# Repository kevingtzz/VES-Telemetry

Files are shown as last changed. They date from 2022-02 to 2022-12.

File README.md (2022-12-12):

## VES-Telemetry 🚀
Telemetry system for electro-solar vehicle VES-KRATOS
## Hardware 🔧
API frames reception and emission for Zigbee mesh topology architecture implemented on Xbee.
CAN protocol data extraction, processing and emission (Low level).
## Software ⚙️
Multi platform aplication on Electron JS for GPS geolocation and electro-solar vehicle data monitoring on real time.
## Initialization:
* Install dependencies with npm install.
* Install RethinkDB, if you have macOS with homebrew just type on your terminal "brew update && brew install rethinkdb".
* Create the database, go to localhost:8080 and create a database with this name "KRATOS-VES".

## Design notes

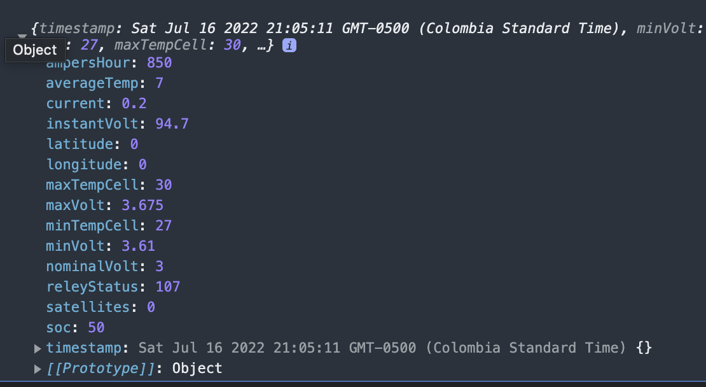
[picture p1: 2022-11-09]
Hardware/PCB/Receiver/Screen Shot 2022-07-16 at 21.05.58.png

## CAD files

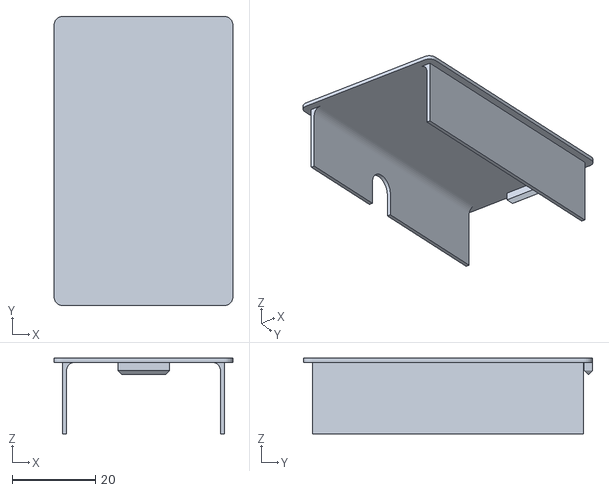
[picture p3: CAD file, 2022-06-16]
Hardware/Cases/Receiver/tapa.stl
43.0 x 69.5 x 18.2

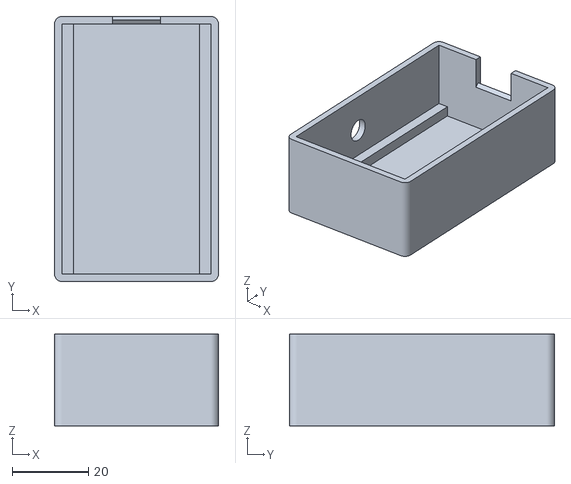
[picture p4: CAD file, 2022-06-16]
Hardware/Cases/Receiver/case.stl
43.0 x 69.5 x 24.0

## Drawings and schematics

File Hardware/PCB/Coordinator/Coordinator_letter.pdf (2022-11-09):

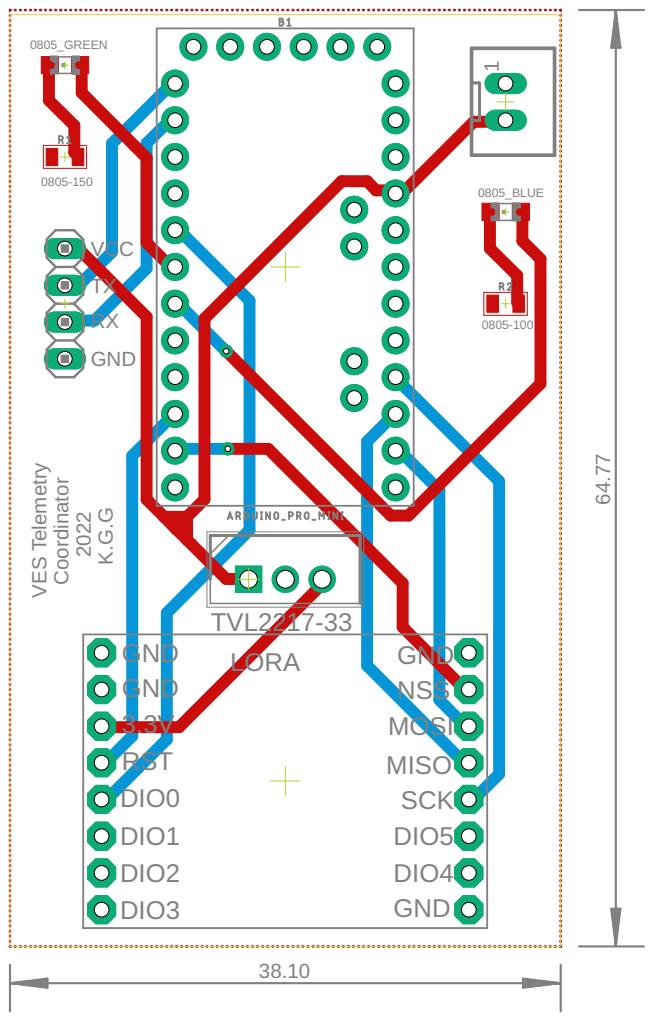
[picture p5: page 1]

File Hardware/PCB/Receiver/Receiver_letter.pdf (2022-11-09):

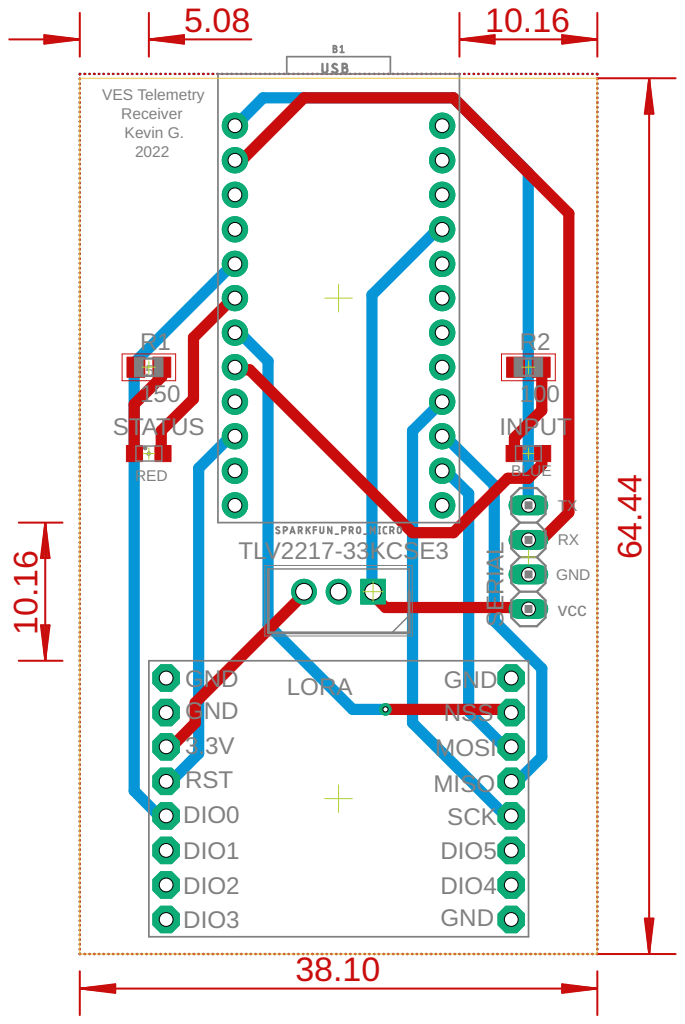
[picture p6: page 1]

VES Telemetry Receiver Kevin G. 2022

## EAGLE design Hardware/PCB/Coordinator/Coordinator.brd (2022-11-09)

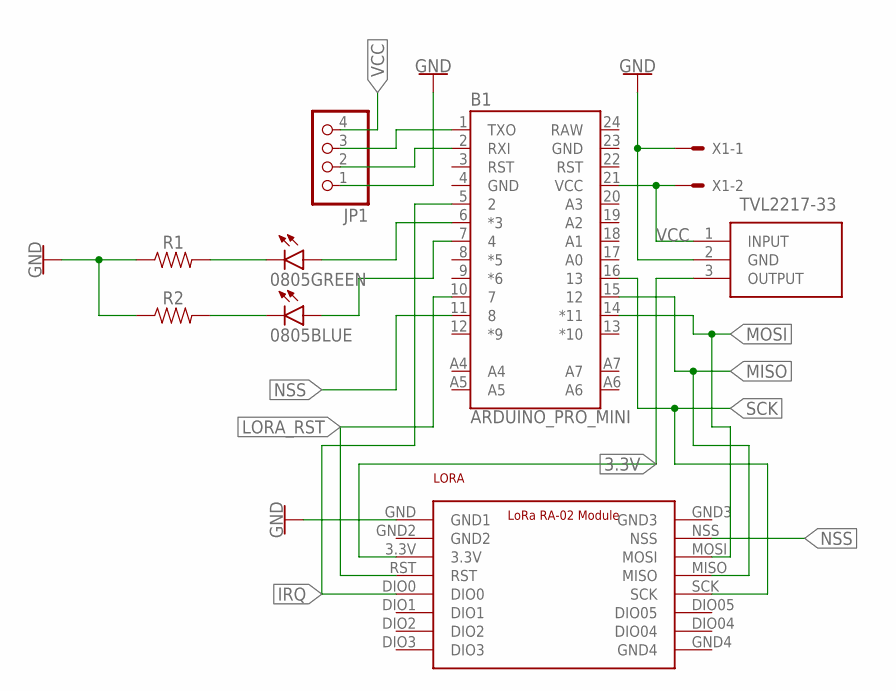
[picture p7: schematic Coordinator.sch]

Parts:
0805BLUE, 0805GREEN: LEDCHIPLED_0805; CHIPLED_0805
B1: ARDUINO_PRO_MINI
JP1: PINHD-1X4; 1X04
LORA: LORA_RA-02_MODULE; LORA_RA-02_MODULE_FOOTPRINT
R1, R2: 0805
TVL2217-33: TLV2217-33KCSE3; TO254P470X1016X1965-3P
X1: JST-XH-02-PIN-LONG-PAD; JST-XH-02-PACKAGE-LONG-PAD

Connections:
3.3V: LORA.3.3V, TVL2217-33.3 (OUTPUT)
GND: B1.4 (GND), B1.23 (GND), JP1.1, LORA.GND (GND1), R1.1, R2.1, TVL2217-33.2 (GND), X1.1
IRQ: B1.5 (2), LORA.DIO0
LORA_RST: B1.10 (7), LORA.RST
MISO: B1.15 (12), LORA.MISO
MOSI: B1.14 (*11), LORA.MOSI
unnamed: B1.2 (RXI), JP1.2
unnamed: B1.1 (TXO), JP1.3
unnamed: 0805GREEN.A, B1.6 (*3)
unnamed: 0805BLUE.A, B1.7 (4)
unnamed: 0805GREEN.C, R1.2
unnamed: 0805BLUE.C, R2.2
NSS: B1.11 (8), LORA.NSS
RAW: B1.24 (RAW)
SCK: B1.16 (13), LORA.SCK
VCC: B1.21 (VCC), JP1.4, TVL2217-33.1 (INPUT), X1.2

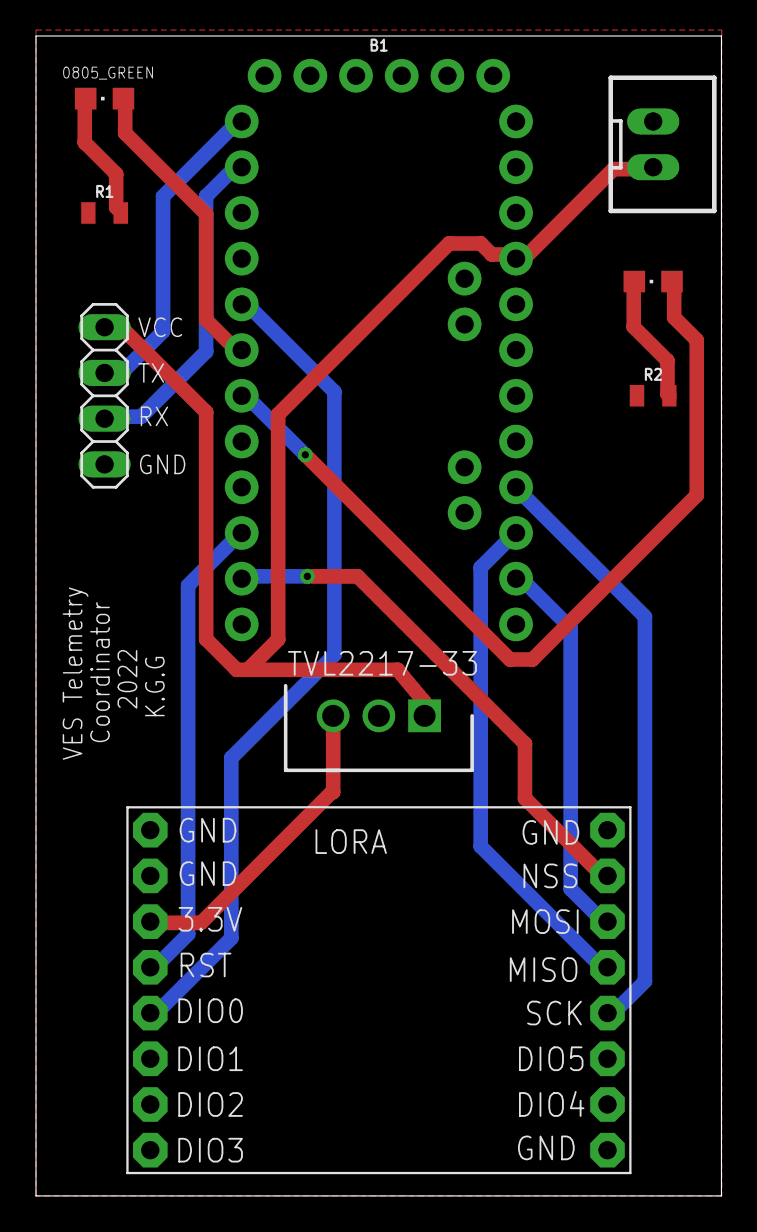
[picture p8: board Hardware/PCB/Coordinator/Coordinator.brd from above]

Board: 2 copper layers, 38.1 x 64.4 mm, 9 parts (0 on the bottom side), 15 nets.

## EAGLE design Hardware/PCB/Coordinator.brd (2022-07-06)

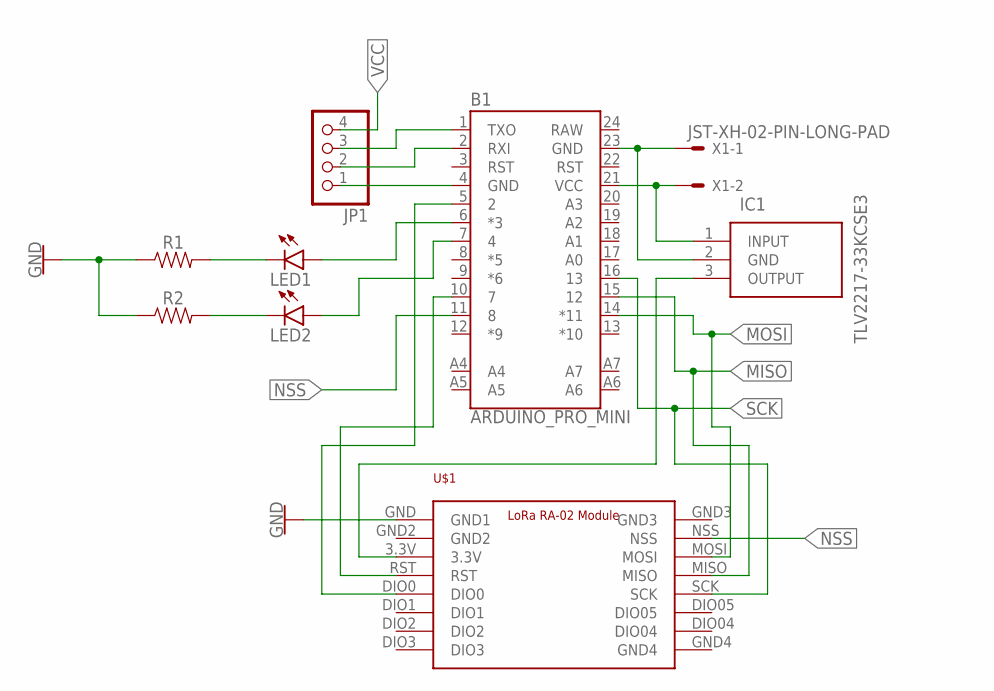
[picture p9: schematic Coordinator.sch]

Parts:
B1: ARDUINO_PRO_MINI
IC1: TLV2217-33KCSE3; TO254P470X1016X1965-3P
JP1: PINHD-1X4; 1X04
LED1, LED2: LEDCHIPLED_0805; CHIPLED_0805
R1, R2: 0805
U$1: LORA_RA-02_MODULE; LORA_RA-02_MODULE_FOOTPRINT
X1: JST-XH-02-PIN-LONG-PAD; JST-XH-02-PACKAGE-LONG-PAD

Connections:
GND: R1.1, R2.1, U$1.GND (GND1)
MISO: B1.15 (12), U$1.MISO
MOSI: B1.14 (*11), U$1.MOSI
unnamed: B1.23 (GND), IC1.2 (GND), X1.1
unnamed: B1.21 (VCC), IC1.1 (INPUT), X1.2
unnamed: IC1.3 (OUTPUT), U$1.3.3V
unnamed: B1.4 (GND), JP1.1
unnamed: B1.2 (RXI), JP1.2
unnamed: B1.1 (TXO), JP1.3
unnamed: B1.5 (2), U$1.DIO0
unnamed: B1.10 (7), U$1.RST
unnamed: B1.6 (*3), LED1.A
unnamed: B1.7 (4), LED2.A
unnamed: LED1.C, R1.2
unnamed: LED2.C, R2.2
NSS: B1.11 (8), U$1.NSS
RAW: B1.24 (RAW)
SCK: B1.16 (13), U$1.SCK
VCC: JP1.4

Board: 2 copper layers, 9 parts (0 on the bottom side), 17 nets, no tracks yet.

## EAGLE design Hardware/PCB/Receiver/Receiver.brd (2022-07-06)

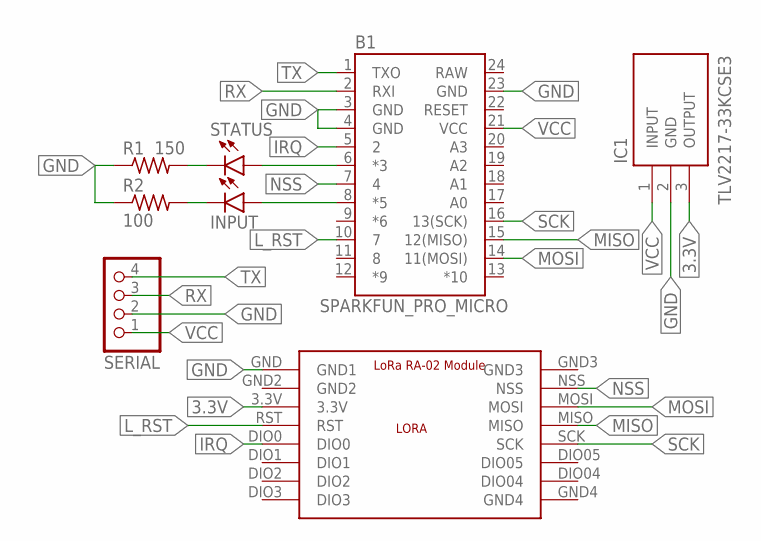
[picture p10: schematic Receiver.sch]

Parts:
B1: SPARKFUN_PRO_MICRO
IC1: TLV2217-33KCSE3; TO254P470X1016X1965-3P
INPUT: LEDSML0805; SML0805
LORA: LORA_RA-02_MODULE; LORA_RA-02_MODULE_FOOTPRINT
R1: 150; R0805
R2: 100; R0805
SERIAL: PINHD-1X4; 1X04
STATUS: LEDSML0805; SML0805

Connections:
3.3V: IC1.3 (OUTPUT), LORA.3.3V
GND: B1.3 (GND), B1.4 (GND), B1.23 (GND), IC1.2 (GND), LORA.GND (GND1), R1.1, R2.1, SERIAL.2
IRQ: B1.5 (2), LORA.DIO0
L_RST: B1.10 (7), LORA.RST
MISO: B1.15 (12(MISO)), LORA.MISO
MOSI: B1.14 (11(MOSI)), LORA.MOSI
unnamed: B1.6 (*3), STATUS.A
unnamed: B1.8 (*5), INPUT.A
unnamed: INPUT.C, R2.2
NSS: B1.7 (4), LORA.NSS
RAW: B1.24 (RAW)
RX: B1.2 (RXI), SERIAL.3
SCK: B1.16 (13(SCK)), LORA.SCK
STATUS: R1.2, STATUS.C
TX: B1.1 (TXO), SERIAL.4
VCC: B1.21 (VCC), IC1.1 (INPUT), SERIAL.1

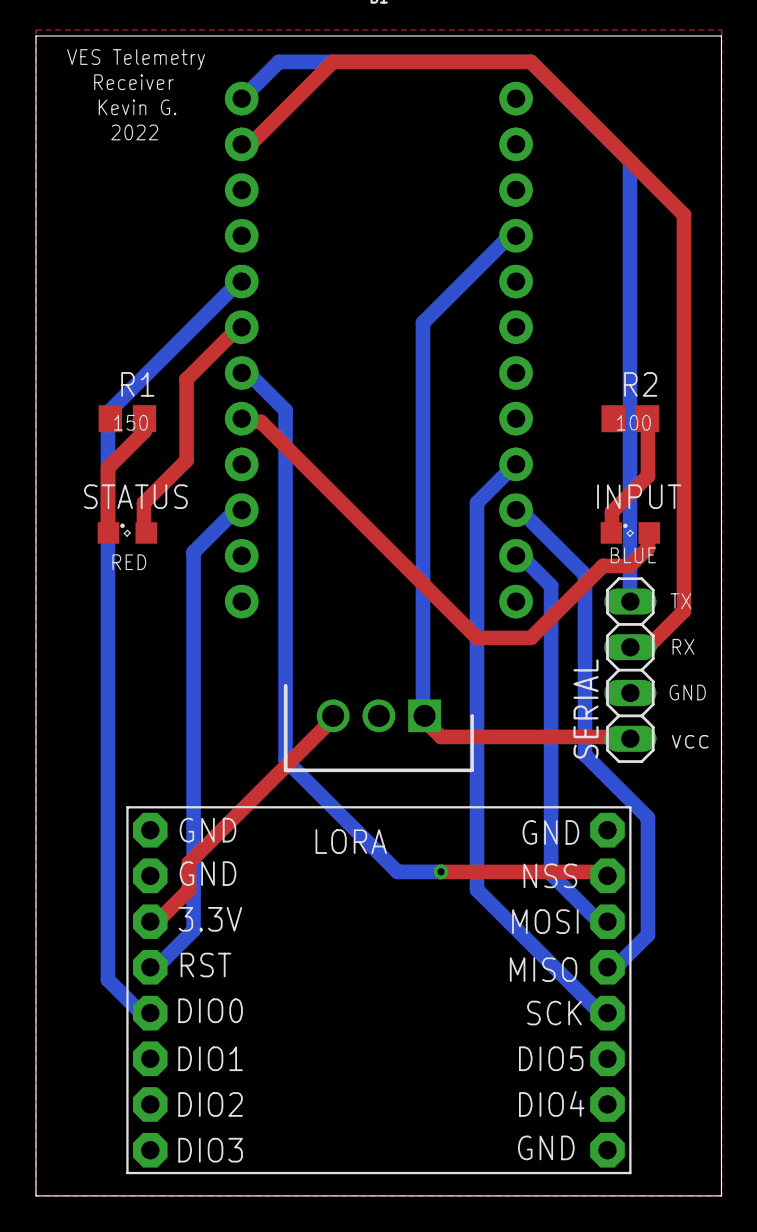
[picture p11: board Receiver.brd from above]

Board: 2 copper layers, 38.1 x 64.4 mm, 8 parts (0 on the bottom side), 15 nets.

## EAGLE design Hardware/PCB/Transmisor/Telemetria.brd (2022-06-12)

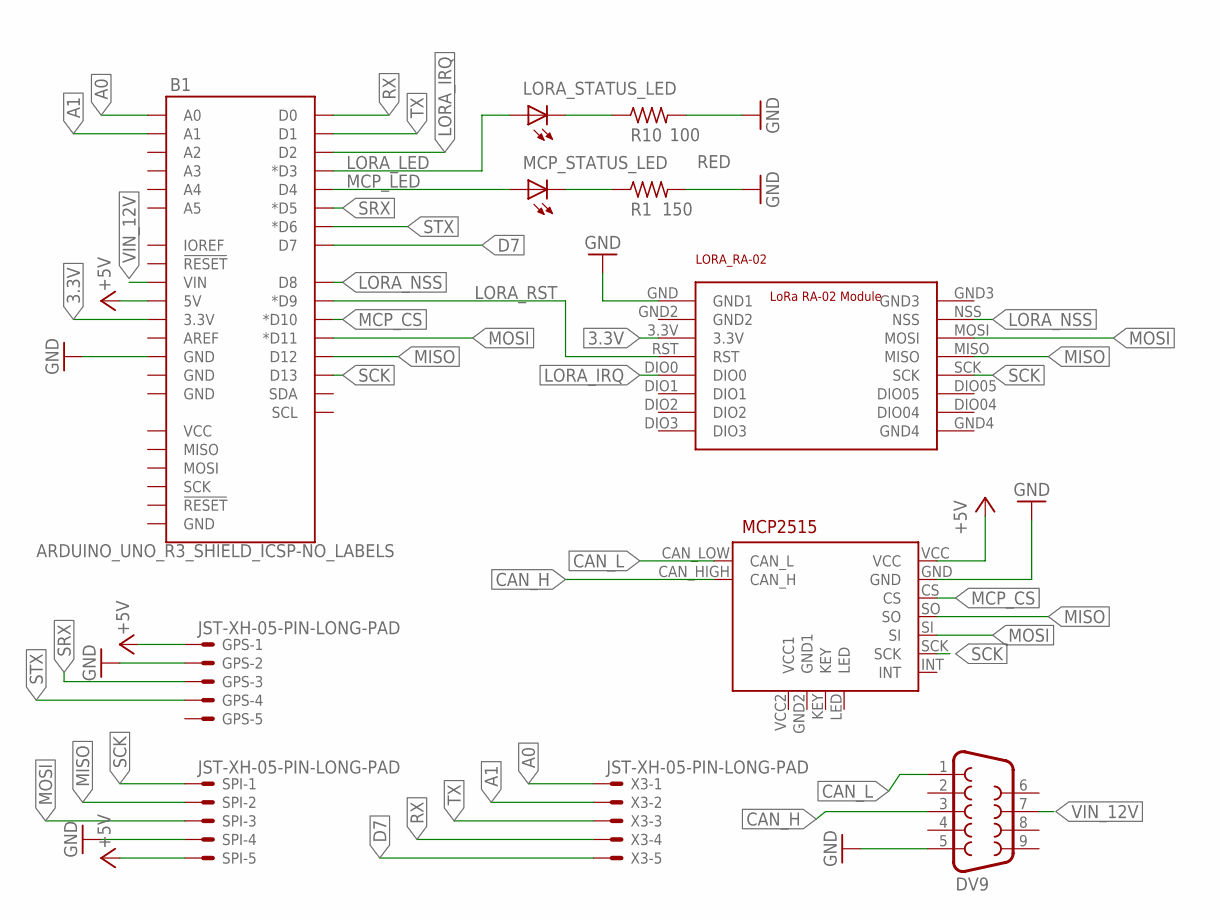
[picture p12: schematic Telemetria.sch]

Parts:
B1: ARDUINO_UNO_R3_SHIELD_ICSP-NO_LABELS; UNO_R3_SHIELD_ICSP_NOLABELS
GPS: JST-XH-05-PIN-LONG-PAD; JST-XH-05-PACKAGE-LONG-PAD
LORA_RA-02: LORA_RA-02_MODULE; LORA_RA-02_MODULE_FOOTPRINT
LORA_STATUS_LED: BLUE; CHIP-LED0805
MCP2515: MCP2515
MCP_STATUS_LED: RED; CHIP-LED0805
R1: 150; M0805
R10: 100; M0805
SPI: JST-XH-05-PIN-LONG-PAD; JST-XH-05-PACKAGE-LONG-PAD
X3: JST-XH-05-PIN-LONG-PAD; JST-XH-05-PACKAGE-LONG-PAD
X4: DV9; F09H

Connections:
3.3V: B1.3.3V, LORA_RA-02.3.3V
+5V: B1.5V, GPS.1, MCP2515.VCC, SPI.5
A0: B1.A0, X3.1
A1: B1.A1, X3.2
CAN_H: MCP2515.CAN_HIGH (CAN_H), X4.3
CAN_L: MCP2515.CAN_LOW (CAN_L), X4.1
D7: B1.D7, X3.5
GND: B1.GND@2 (GND), GPS.2, LORA_RA-02.GND (GND1), MCP2515.GND, R1.2, R10.2, SPI.4, X4.5
LORA_IRQ: B1.D2, LORA_RA-02.DIO0
LORA_LED: B1.D3 (*D3), LORA_STATUS_LED.A
LORA_NSS: B1.D8, LORA_RA-02.NSS
LORA_RST: B1.D9 (*D9), LORA_RA-02.RST
MCP_CS: B1.D10 (*D10), MCP2515.CS
MCP_LED: B1.D4, MCP_STATUS_LED.A
MISO: B1.D12, LORA_RA-02.MISO, MCP2515.SO, SPI.2
MOSI: B1.D11 (*D11), LORA_RA-02.MOSI, MCP2515.SI, SPI.3
unnamed: LORA_STATUS_LED.C, R10.1
unnamed: MCP_STATUS_LED.C, R1.1
RX: B1.RX (D0), X3.4
SCK: B1.D13, LORA_RA-02.SCK, MCP2515.SCK, SPI.1
SRX: B1.D5 (*D5), GPS.3
STX: B1.D6 (*D6), GPS.4
TX: B1.TX (D1), X3.3
VIN_12V: B1.VIN, X4.7

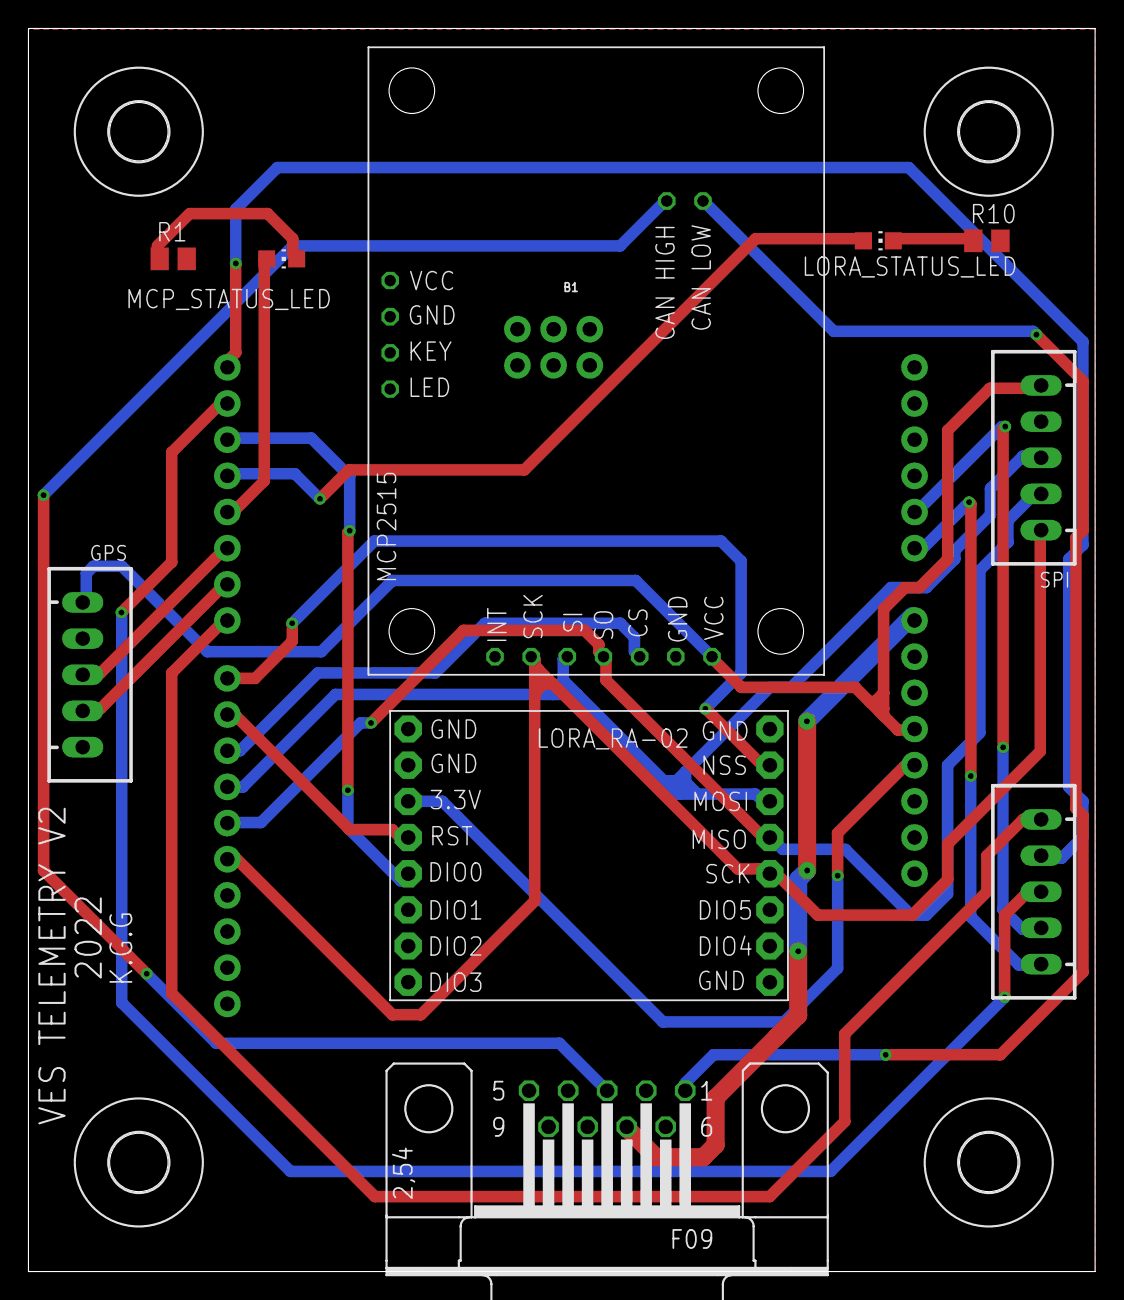
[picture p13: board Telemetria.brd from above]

Board: 2 copper layers, 74.9 x 87.3 mm, 15 parts (0 on the bottom side), 24 nets.

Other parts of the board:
U$1, U$2, U$3, U$4: 4,1

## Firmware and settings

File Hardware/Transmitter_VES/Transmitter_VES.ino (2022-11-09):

#include "constants.h"
#include <SPI.h>
#include <mcp_can.h>
#include <LoRa.h>
#include <TinyGPSPlus.h>
#include <SoftwareSerial.h>

MCP_CAN CAN(CAN_SPI_CS_PIN);
byte data[DATA_LENGTH] = { 0 };
byte frame[FRAME_LENGTH] = { 0 };
byte buf[DATA_LENGTH];

TinyGPSPlus gps;
SoftwareSerial gps_ss(GPS_RX_PIN, GPS_TX_PIN);

long lat = 0;
long lng = 0;

unsigned int current_time = 0;
unsigned int led_lora_current_time = 0;
unsigned int final_time = 0;
unsigned int led_lora_final_time = 0;

void fill_data_can() {
  unsigned char len = 0;
  unsigned char buf[8];

  CAN.readMsgBuf(&len, buf);

  unsigned long canId = CAN.getCanId();
//  Serial.println(canId);

  if (canId == 0x3CB) {
//    Serial.println("0x3CB data");
    data[0] = buf[2]; // most significant minVolt byte
    data[1] = buf[3]; // least significant minVolt byte
    data[2] = buf[4]; // most significant maxVolt byte
    data[3] = buf[5]; // least significant maxVolt byte
    data[4] = buf[6]; // minimum temperature
    data[5] = buf[7]; // maximum temperature
  }
  if (canId == 0x03B) {
//    Serial.println("0x03B data");
    data[6] = buf[0]; // most significant current byte
    data[7] = buf[1]; // least significant current byte
    data[8] = buf[2]; // most significant instantVolt byte
    data[9] = buf[3]; // least significant instantVolt byte
    data[10] = buf[4]; // Ampers per hour most significant byte
    data[11] = buf[5]; // Ampers per hour least significant byte
    data[12] = buf[6]; // SOC
  }
  if (canId == 0x653) {
//    Serial.println("0x653 data");
    data[13] = buf[0]; // reley status
    data[14] = buf[4]; // average temp - div by 2
  }
  if (canId == 0x651) {
//    Serial.println("0x651 data");
    data[15] = buf[4]; // Nominal volt most significant byte
    data[16] = buf[5]; // Nominal volt leat significant byte
  }
  if (canId == 0x3A) {
    Serial.println("0x03A data");
  }
}

void fill_data_gps() {
  while(gps_ss.available() > 0) {
    gps.encode(gps_ss.read());
  }
  if (gps.satellites.isValid() && gps.satellites.isUpdated()) {
    data[17] = gps.satellites.value();
  } else if (gps.location.isValid() && gps.location.isUpdated()) {
    lat = gps.location.lat()*pow(10, 6);
    lng = gps.location.lng()*pow(10, 6);
    data[18] = (0x000000FF)&lat;
    data[19] = ((0x0000FF00)&lat) >> 8;
    data[20] = ((0x00FF0000)&lat) >> 16;
    data[21] = ((0xFF000000)&lat) >> 24;
    data[22] = (0x000000FF)&lng;
    Serial.print(data[22]);
    Serial.print(",");
    data[23] = ((0x0000FF00)&lng) >> 8;
    Serial.print(data[23]);
    Serial.print(",");
    data[24] = ((0x00FF0000)&lng) >> 16;
    Serial.print(data[24]);
    Serial.print(",");
    data[25] = ((0xFF000000)&lng) >> 24;
    Serial.print(data[25]);
    Serial.println("");
  }
}

void fillDataTest() {
  data[0] = 0x03;
  data[12] = 50;
  data[DATA_LENGTH - 1] = 0x03;
}

//byte checksum(byte data[]) {
//  byte checksum = 0x00;
//  for (int i = 0; i < DATA_LENGTH; i++) {
//      checksum += data[i];
//  }
//  return checksum;
//}

void fillFrame() {
  frame[0] = NETWORK_ID;
  frame[1] = TRANSMITTER_ADDRESS;
  frame[2] = DATA_LENGTH;
  for (int i = 3; i < FRAME_LENGTH; i++) {
    frame[i] = data[i - 3];
  }
//  frame[FRAME_LENGTH - 1] = checksum(data);
}

void sendFrame() {
  digitalWrite(LORA_STATUS_LED, HIGH);
  
  fillFrame();
//  printFrame();
  Serial.println("Sending package...");
  LoRa.beginPacket();
  LoRa.write(frame, FRAME_LENGTH);
  LoRa.endPacket();
}

//void printFrame() {
//  Serial.print("CheckSum: ");
//  Serial.println(frame[FRAME_LENGTH - 1]);
//}

void setup() {
  pinMode(LORA_STATUS_LED, OUTPUT);
  pinMode(MCP_STATUS_LED, OUTPUT);
//  pinMode(2, INPUT);

  LoRa.setPins(LORA_CS_PIN, LORA_RESET_PIN, LORA_IRQ_PIN);

  Serial.begin(SERIAL_BAUD_RATE);
  while(!Serial);
  gps_ss.begin(GPS_BAUD_RATE);

  if (!LoRa.begin(LORA_FREQUENCY)) {
    Serial.println("Starting LoRa failed!");
    while (1);
  }
  Serial.println("Starting LoRa Successfull!");
  digitalWrite(LORA_STATUS_LED, HIGH);
  LoRa.setTxPower(20);

  while (CAN_OK != CAN.begin(CAN_500KBPS)) {
    Serial.println("CAN init failed!!");
    delay(100);
  }
  Serial.println("CAN ok");
  digitalWrite(MCP_STATUS_LED, HIGH);
}

void loop() {
  if (CAN_MSGAVAIL == CAN.checkReceive()) {
    fill_data_can();
  }

  if (gps_ss.available() > 0) {
      fill_data_gps();
  }

  current_time = millis();
  led_lora_current_time = millis();
  
  if (current_time - final_time > 500) {
//    fillDataTest();
    sendFrame();
    memset(data, 0, DATA_LENGTH); // reset data vecto to 0
    final_time = current_time;
  }

  if (led_lora_current_time - led_lora_final_time > 1000) {
    digitalWrite(LORA_STATUS_LED, LOW);
    led_lora_final_time = led_lora_current_time;  
  }
}

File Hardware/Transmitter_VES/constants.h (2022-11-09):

//========================== Pins ==============================//

#define CAN_SPI_CS_PIN 10
#define LORA_CS_PIN 8
#define LORA_RESET_PIN 9
#define LORA_IRQ_PIN 2
#define LORA_STATUS_LED 3
#define MCP_STATUS_LED 4
#define GPS_RX_PIN 5
#define GPS_TX_PIN 6

//========================== Settings ==============================//

#define SERIAL_BAUD_RATE 9600
#define GPS_BAUD_RATE 9600
#define DATA_LENGTH 26
#define FRAME_LENGTH DATA_LENGTH + 3

//========================== Mesh settings ========================//

#define LORA_FREQUENCY 433E6
#define TRANSMITTER_ADDRESS 0x1
#define COORDINATOR_ADDRESS 0x2
#define RECEIVER_ADDRESS 0x3
#define NETWORK_ID 0x7

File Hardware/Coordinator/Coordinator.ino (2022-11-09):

#include <SPI.h>
#include <LoRa.h>
#include "constants.h"

unsigned int input_led_current_time = 0;
unsigned int input_led_final_time = 0;

void fillFrame(byte frame[], int data_length, int frame_length, byte data[]) {
  frame[0] = NETWORK_ID;
  frame[1] = COORDINATOR_ADDRESS;
  frame[2] = data_length;
  for (int i = 3; i < frame_length; i++) {
    frame[i] = data[i - 3];
  }
//  frame[FRAME_LENGTH - 1] = checksum(data);
}

void send_frame(byte frame[], int frame_length) {
//  printFrame();
  Serial.println("Sending package...");
  LoRa.beginPacket();
  LoRa.write(frame, frame_length);
  LoRa.endPacket();
}

void setup() {
  pinMode(LORA_INPUT_LED, OUTPUT);
  pinMode(LORA_STATUS_LED, OUTPUT);
  Serial.begin(SERIAL_BAUD_RATE);

  LoRa.setPins(LORA_CS_PIN, LORA_RESET_PIN, LORA_IRQ_PIN);
  if (!LoRa.begin(LORA_FREQUENCY)) {
    while (1);
    Serial.println("LoRa init failed!!");
  }
  Serial.println("Starting LoRa Successfull!");
  digitalWrite(LORA_STATUS_LED, HIGH);
}

void loop() {
  input_led_current_time = millis();
  int packetSize = LoRa.parsePacket();
  if (packetSize) {
    if (LoRa.read() == NETWORK_ID) {
      if (LoRa.read() == TRANSMITTER_ADDRESS) {
        digitalWrite(LORA_INPUT_LED, HIGH);
        int data_length = LoRa.read();
        int frame_length = data_length + 3;
        byte data[data_length] = { 0 };
        int index = 0;  
        while (LoRa.available()) {
          data[index] = LoRa.read();
          index++;
        }
        byte frame[data_length] = { 0 };
        fillFrame(frame, data_length, frame_length, data);
        send_frame(frame, frame_length);
      }
    }  
  }

  if (input_led_current_time - input_led_final_time > 1000) {
    digitalWrite(LORA_INPUT_LED, LOW);
    input_led_final_time = input_led_current_time;  
  }
}

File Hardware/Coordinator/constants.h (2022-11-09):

//========================== Pins ==============================//

#define LORA_CS_PIN 8
#define LORA_RESET_PIN 7
#define LORA_IRQ_PIN 2
#define LORA_INPUT_LED 4
#define LORA_STATUS_LED 3

//========================== Settings ==============================//

#define SERIAL_BAUD_RATE 9600

//========================== Mesh settings ========================//

#define LORA_FREQUENCY 433E6
#define TRANSMITTER_ADDRESS 0x1
#define COORDINATOR_ADDRESS 0x2
#define RECEIVER_ADDRESS 0x3
#define NETWORK_ID 0x7

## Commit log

2022-06-12 feat(Transmissor): PCB Transmissor finished
    [Telemetria.brd, Telemetria.sch]
2022-06-12 fix(transmissor): transmisson pcb updated
    [Telemetria.brd, Telemetria.sch]
2022-06-16 receiver case v1
    [case.stl, tapa.stl]
2022-07-06 feat(protocol&PCB): RadioHead router protocol done, receiver pcb done
    [Coordinator.brd, Coordinator.sch, Receiver.brd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]
2022-11-09 commit after race
    [Coordinator.brd, Coordinator.sch]

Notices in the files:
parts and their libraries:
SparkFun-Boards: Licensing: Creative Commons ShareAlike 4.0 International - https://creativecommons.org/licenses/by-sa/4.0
